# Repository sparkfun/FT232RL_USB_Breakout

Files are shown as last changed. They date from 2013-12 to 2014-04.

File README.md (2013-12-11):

FT232RL USB Breakout
====================

[FT232RL USB to Serial Breakout Board
*FT232RL USB to Serial Breakout Board (BOB-00718)*](https://www.sparkfun.com/products/718)

This is a basic breakout board for FTDI's popular USB to UART IC.
VCCIO is tied to 3.3V through a solder jumper. 

Repository Contents
-------------------
* **/Hardware** - All Eagle design files (.brd, .sch)

License Information
-------------------
The hardware is released under [Creative Commons Share-alike 3.0](http://creativecommons.org/licenses/by-sa/3.0/).  
All other code is open source so please feel free to do anything you want with it; you buy me a beer if you use this and we meet someday ([Beerware license](http://en.wikipedia.org/wiki/Beerware)).

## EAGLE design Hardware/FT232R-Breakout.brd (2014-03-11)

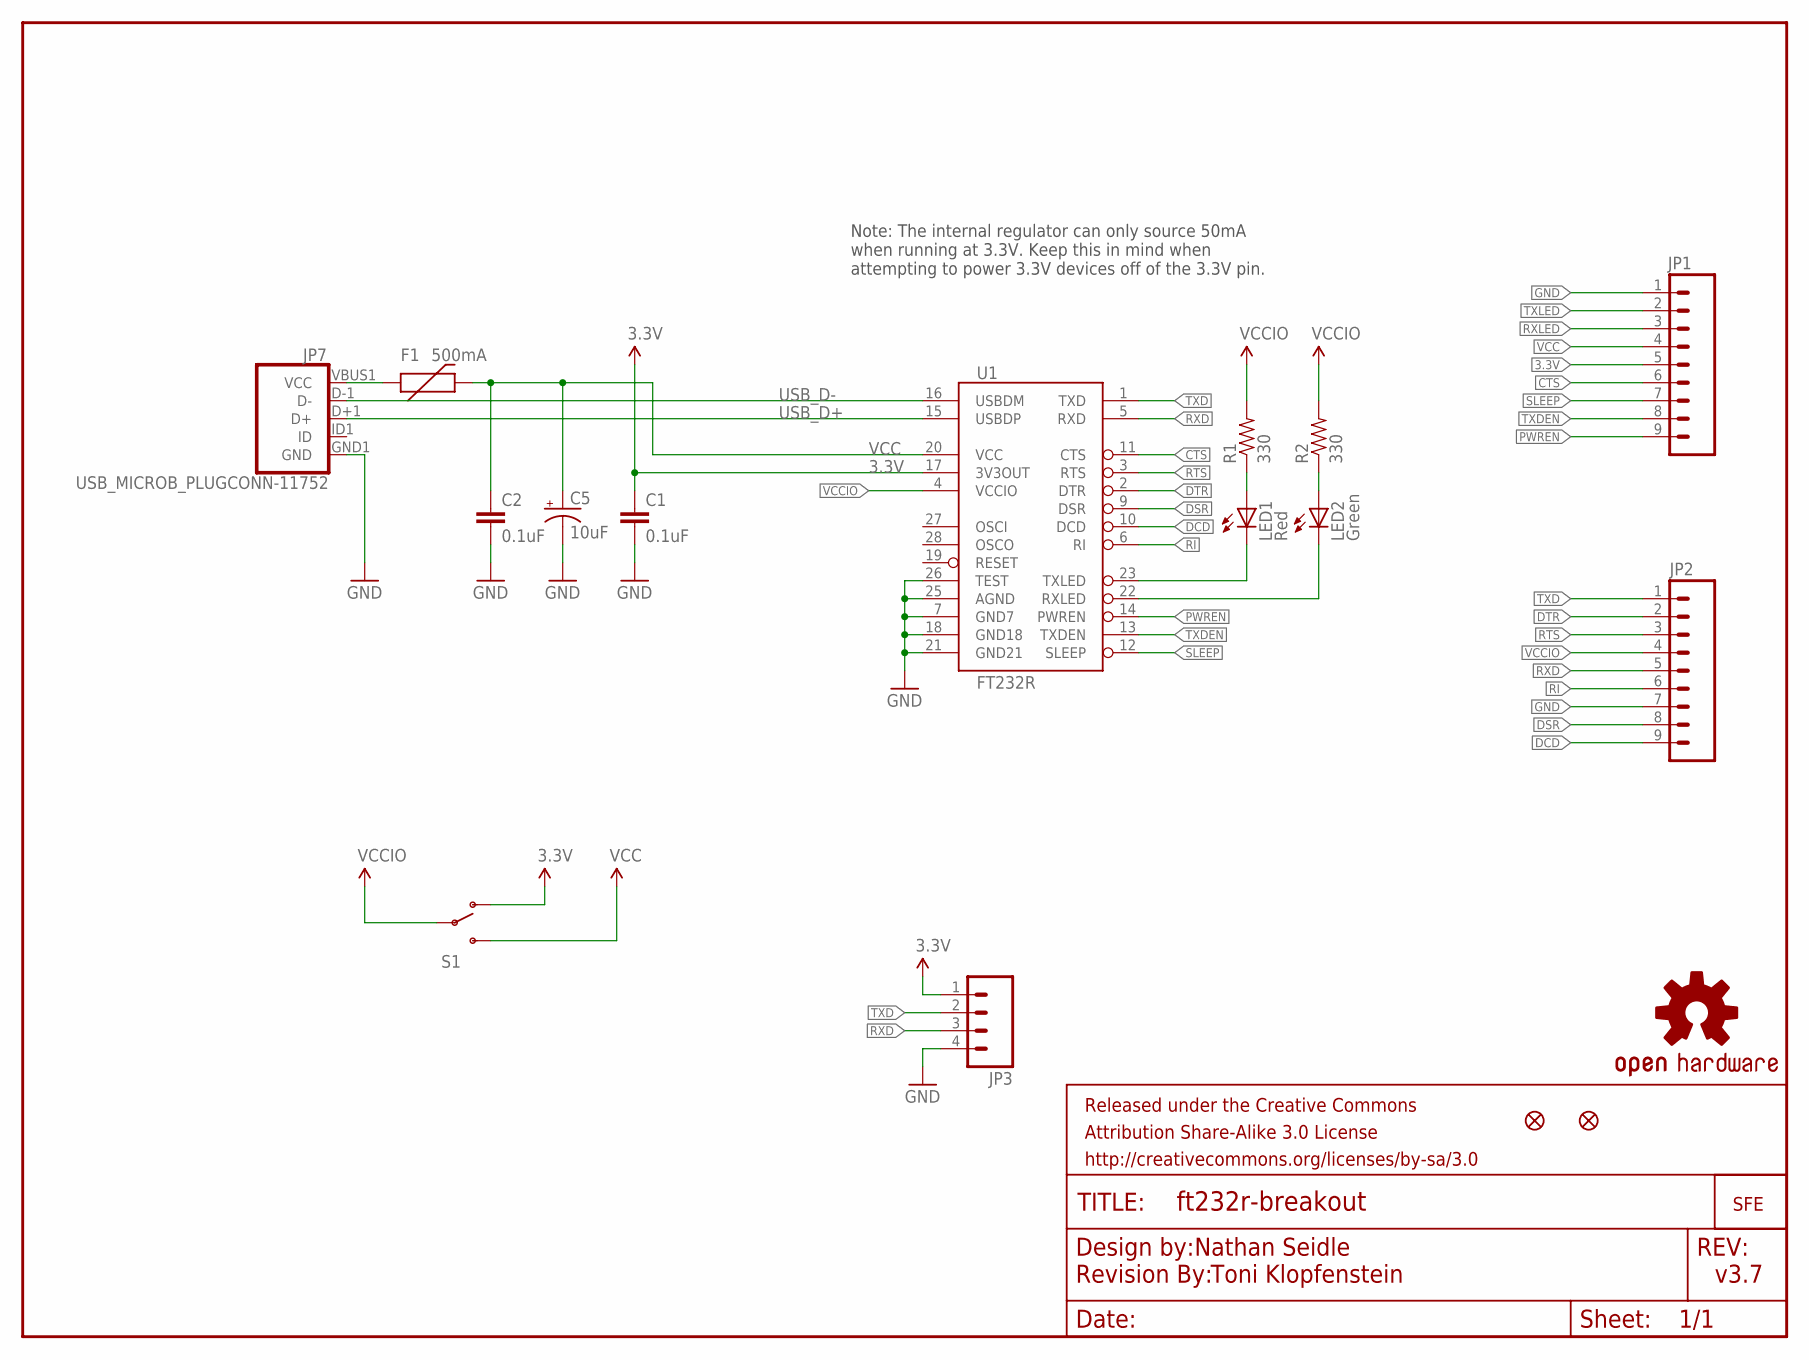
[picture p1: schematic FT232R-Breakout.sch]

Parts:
C1, C2: 0.1uF; 0603-CAP
C5: 10uF; EIA3216
F1: 500mA; PTC-1206
FRAME1: FRAME-LETTER; CREATIVE_COMMONS
JP1, JP2: M09; 1X09
JP3: M04PTH; 1X04
JP5, JP6: FIDUCIAL1X2; FIDUCIAL-1X2
JP7: USB_MICROB_PLUGCONN-11752; USB-B-MICRO-SMD_V03
LED1: Red; LED-0603
LED2: Green; LED-0603
LOGO1: OSHW-LOGOS; OSHW-LOGO-S
R1, R2: 330; 0603-RES
S1: SWITCH-SPDTSMD; AYZ0202
U1: FT232R; SSOP28DB
U$1: REVISION
U$2: LOGO-SFENEW; SFE-NEW-WEBLOGO

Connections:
3.3V: C1.1, JP1.5, JP3.1, S1.1 (O), U1.17 (3V3OUT)
CTS: JP1.6, U1.11 (CTS)
DCD: JP2.9, U1.10 (DCD)
DSR: JP2.8, U1.9 (DSR)
DTR: JP2.2, U1.2 (DTR)
GND: C1.2, C2.2, C5.C (-), JP1.1, JP2.7, JP3.4, JP7.GND1 (GND), U1.7 (GND7), U1.18 (GND18), U1.21 (GND21), U1.25 (AGND), U1.26 (TEST)
unnamed: LED1.A, R1.1
unnamed: LED2.A, R2.1
unnamed: F1.1, JP7.VBUS1 (VCC)
PWREN: JP1.9, U1.14 (PWREN)
RI: JP2.6, U1.6 (RI)
RTS: JP2.3, U1.3 (RTS)
RXD: JP2.5, JP3.3, U1.5 (RXD)
RXLED: JP1.3, LED2.C, U1.22 (RXLED)
SLEEP: JP1.7, U1.12 (SLEEP)
TXD: JP2.1, JP3.2, U1.1 (TXD)
TXDEN: JP1.8, U1.13 (TXDEN)
TXLED: JP1.2, LED1.C, U1.23 (TXLED)
USB_D+: JP7.D+1 (D+), U1.15 (USBDP)
USB_D-: JP7.D-1 (D-), U1.16 (USBDM)
VCC: C2.1, C5.A (+), F1.2, JP1.4, S1.3 (S), U1.20 (VCC)
VCCIO: JP2.4, R1.2, R2.2, S1.2, U1.4 (VCCIO)

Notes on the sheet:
v3.7
Nathan Seidle
Toni Klopfenstein
Note: The internal regulator can only source 50mA when running at 3.3V. Keep this in mind when attempting to power 3.3V devices off of the 3.3V pin.

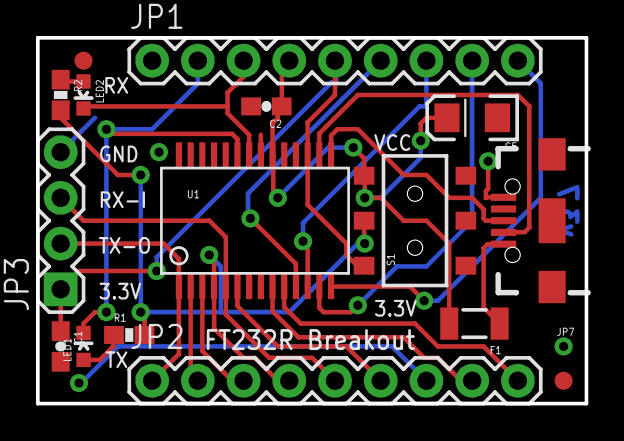
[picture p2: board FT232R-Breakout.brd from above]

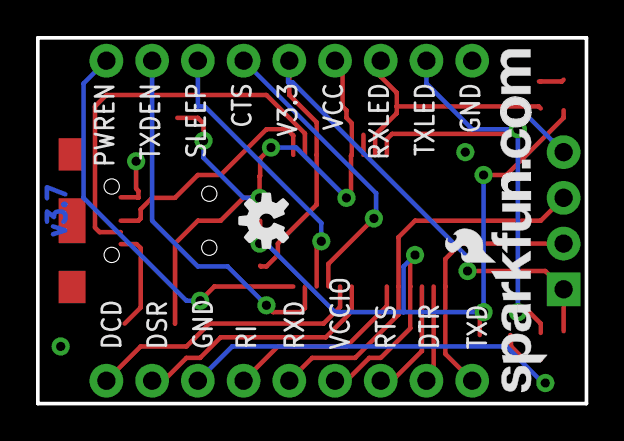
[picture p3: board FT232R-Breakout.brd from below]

Board: 2 copper layers, 30.5 x 20.3 mm, 20 parts (2 on the bottom side), 22 nets.

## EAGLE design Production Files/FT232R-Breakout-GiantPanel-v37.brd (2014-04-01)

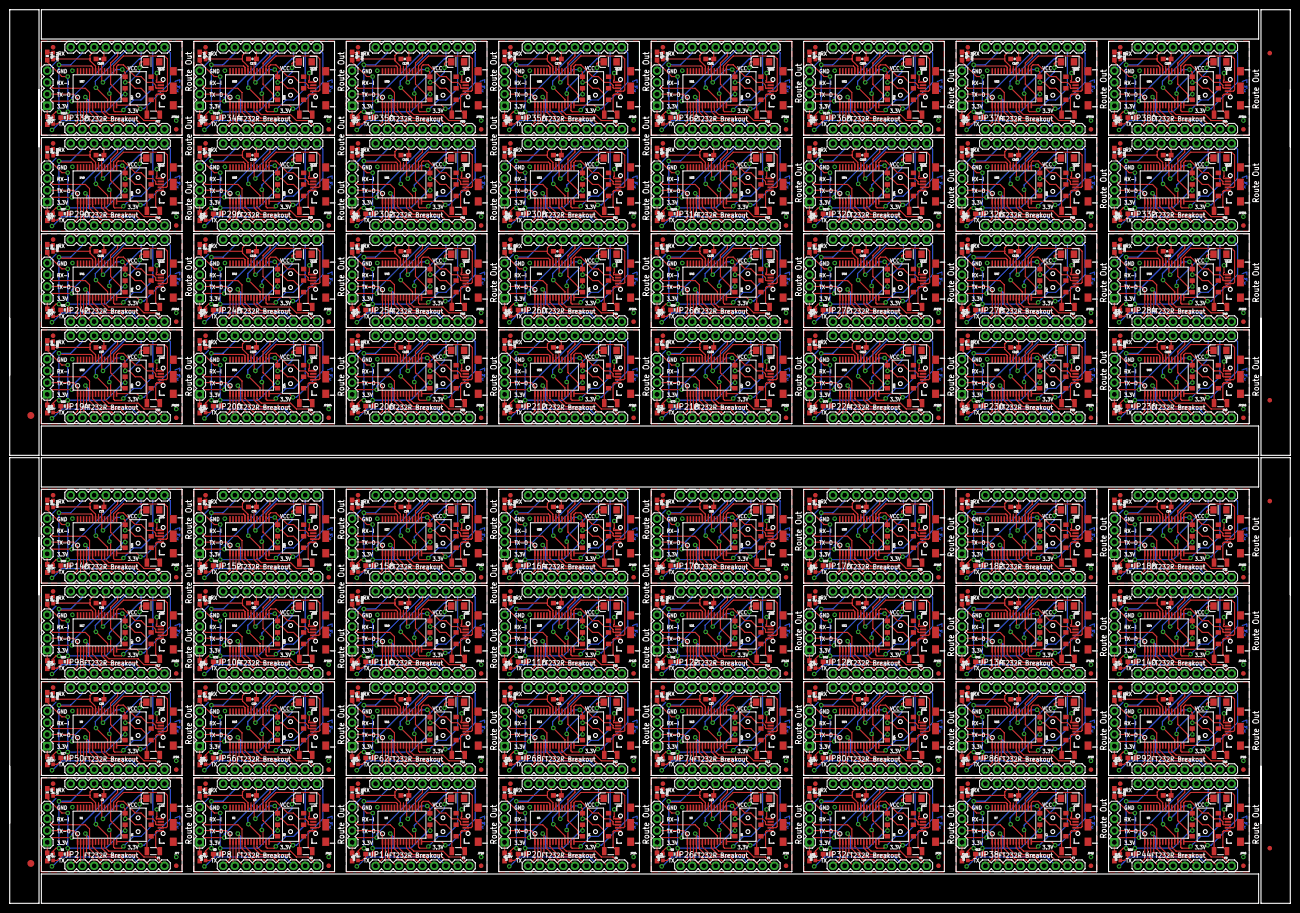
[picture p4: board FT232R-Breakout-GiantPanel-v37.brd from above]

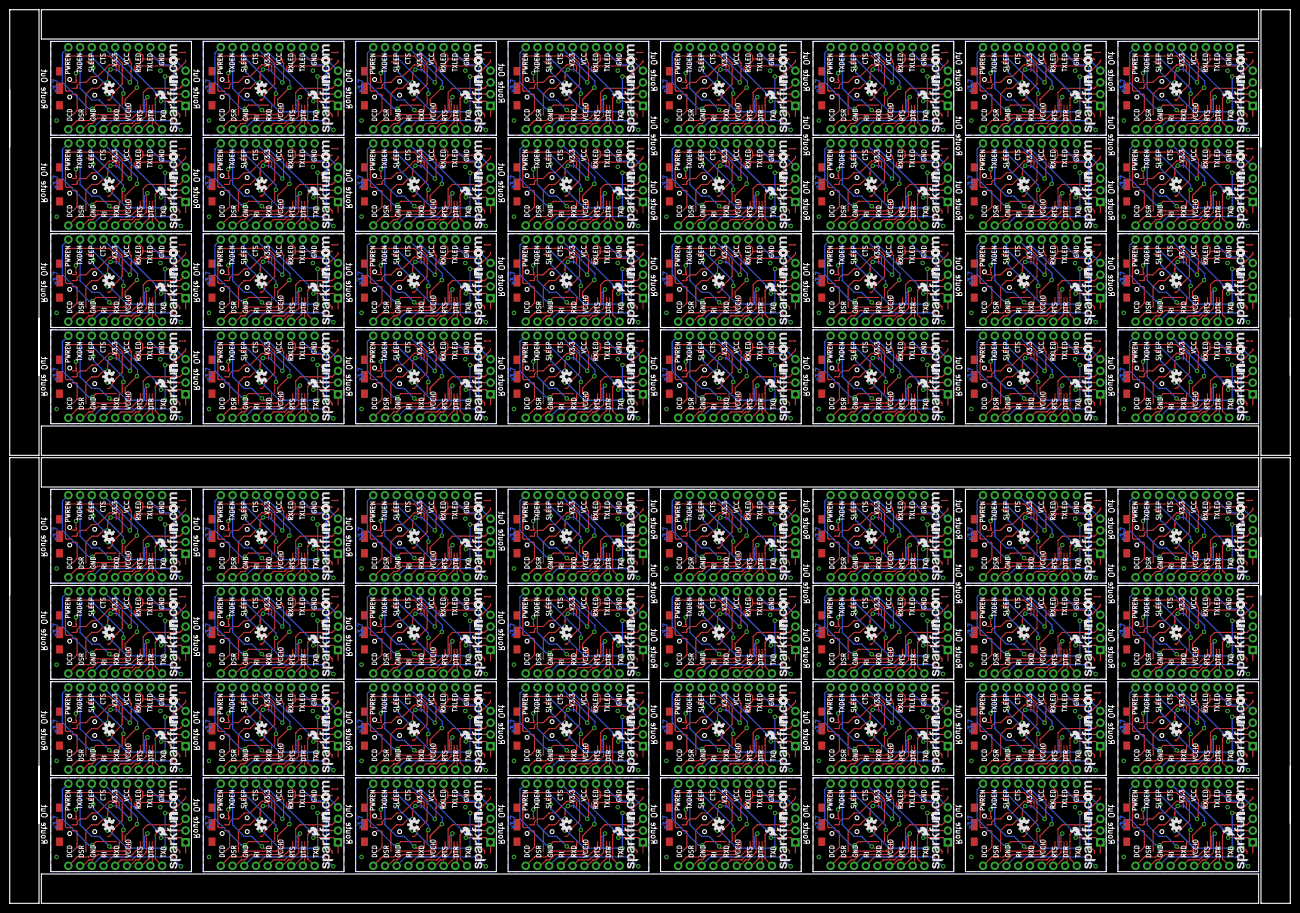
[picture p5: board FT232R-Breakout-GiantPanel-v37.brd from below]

Board: 2 copper layers, 277.4 x 193.5 mm, 1158 parts (128 on the bottom side), 1408 nets.

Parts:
C1, C2, C3, C6, C7, C9, C10, C12, C13, C15, C16, C18, C19, C21, C22, C24, C25, C27, C28, C30, C31, C33, C34, C36, C37, C39, C40, C42, C43, C45, C46, C48, C49, C51, C52, C54, C55, C57, C58, C60, C61, C63, C64, C66, C67, C69, C70, C72, C73, C75, C76, C78, C79, C81, C82, C84, C85, C87, C88, C90, C91, C93, C94, C96, C97, C99, C100, C102, C103, C105, C106, C108, C109, C111, C112, C114, C115, C117, C118, C120, C121, C123, C124, C126, C127, C129, C130, C132, C133, C135, C136, C138, C139, C141, C142, C144, C145, C147, C148, C150, C151, C153, C154, C156, C157, C159, C160, C162, C163, C165, C166, C168, C169, C171, C172, C174, C175, C177, C178, C180, C181, C183, C184, C186, C187, C189, C190, C192: 0.1uF; 0603-CAP
C4, C5, C8, C11, C14, C17, C20, C23, C26, C29, C32, C35, C38, C41, C44, C47, C50, C53, C56, C59, C62, C65, C68, C71, C74, C77, C80, C83, C86, C89, C92, C95, C98, C101, C104, C107, C110, C113, C116, C119, C122, C125, C128, C131, C134, C137, C140, C143, C146, C149, C152, C155, C158, C161, C164, C167, C170, C173, C176, C179, C182, C185, C188, C191: 10uF; EIA3216
E$1, E$4: FIDUCIAL-1.5X3
E$2, E$3, E$6, E$8: FIDUCIAL-1X2
F1, F2, F3, F4, F5, F6, F7, F8, F9, F10, F11, F12, F13, F14, F15, F16, F17, F18, F19, F20, F21, F22, F23, F24, F25, F26, F27, F28, F29, F30, F31, F32, F33, F34, F35, F36, F37, F38, F39, F40, F41, F42, F43, F44, F45, F46, F47, F48, F49, F50, F51, F52, F53, F54, F55, F56, F57, F58, F59, F60, F61, F62, F63, F64: 500mA; PTC-1206
JP1, JP2, JP4, JP8, JP13, JP14, JP19, JP20, JP25, JP26, JP31, JP32, JP37, JP38, JP43, JP44, JP49, JP50, JP55, JP56, JP61, JP62, JP67, JP68, JP73, JP74, JP79, JP80, JP85, JP86, JP91, JP92, JP97, JP98, JP103, JP104, JP109, JP110, JP115, JP116, JP121, JP122, JP127, JP128, JP133, JP134, JP139, JP140, JP145, JP146, JP151, JP152, JP157, JP158, JP163, JP164, JP169, JP170, JP175, JP176, JP181, JP182, JP187, JP188, JP193, JP194, JP199, JP200, JP205, JP206, JP211, JP212, JP217, JP218, JP223, JP224, JP229, JP230, JP235, JP236, JP241, JP242, JP247, JP248, JP253, JP254, JP259, JP260, JP265, JP266, JP271, JP272, JP277, JP278, JP283, JP284, JP289, JP290, JP295, JP296, JP301, JP302, JP307, JP308, JP313, JP314, JP319, JP320, JP325, JP326, JP331, JP332, JP337, JP338, JP343, JP344, JP349, JP350, JP355, JP356, JP361, JP362, JP367, JP368, JP373, JP374, JP379, JP380: 1X09
JP3, JP9, JP15, JP21, JP27, JP33, JP39, JP45, JP51, JP57, JP63, JP69, JP75, JP81, JP87, JP93, JP99, JP105, JP111, JP117, JP123, JP129, JP135, JP141, JP147, JP153, JP159, JP165, JP171, JP177, JP183, JP189, JP195, JP201, JP207, JP213, JP219, JP225, JP231, JP237, JP243, JP249, JP255, JP261, JP267, JP273, JP279, JP285, JP291, JP297, JP303, JP309, JP315, JP321, JP327, JP333, JP339, JP345, JP351, JP357, JP363, JP369, JP375, JP381: 1X04
JP5, JP6, JP10, JP11, JP16, JP17, JP22, JP23, JP28, JP29, JP34, JP35, JP40, JP41, JP46, JP47, JP52, JP53, JP58, JP59, JP64, JP65, JP70, JP71, JP76, JP77, JP82, JP83, JP88, JP89, JP94, JP95, JP100, JP101, JP106, JP107, JP112, JP113, JP118, JP119, JP124, JP125, JP130, JP131, JP136, JP137, JP142, JP143, JP148, JP149, JP154, JP155, JP160, JP161, JP166, JP167, JP172, JP173, JP178, JP179, JP184, JP185, JP190, JP191, JP196, JP197, JP202, JP203, JP208, JP209, JP214, JP215, JP220, JP221, JP226, JP227, JP232, JP233, JP238, JP239, JP244, JP245, JP250, JP251, JP256, JP257, JP262, JP263, JP268, JP269, JP274, JP275, JP280, JP281, JP286, JP287, JP292, JP293, JP298, JP299, JP304, JP305, JP310, JP311, JP316, JP317, JP322, JP323, JP328, JP329, JP334, JP335, JP340, JP341, JP346, JP347, JP352, JP353, JP358, JP359, JP364, JP365, JP370, JP371, JP376, JP377, JP382, JP383: FIDUCIAL1X2; FIDUCIAL-1X2
JP7, JP12, JP18, JP24, JP30, JP36, JP42, JP48, JP54, JP60, JP66, JP72, JP78, JP84, JP90, JP96, JP102, JP108, JP114, JP120, JP126, JP132, JP138, JP144, JP150, JP156, JP162, JP168, JP174, JP180, JP186, JP192, JP198, JP204, JP210, JP216, JP222, JP228, JP234, JP240, JP246, JP252, JP258, JP264, JP270, JP276, JP282, JP288, JP294, JP300, JP306, JP312, JP318, JP324, JP330, JP336, JP342, JP348, JP354, JP360, JP366, JP372, JP378, JP384: USB_MICROB_PLUGCONN-11752; USB-B-MICRO-SMD_V03
LED1, LED3, LED5, LED7, LED9, LED11, LED13, LED15, LED17, LED19, LED21, LED23, LED25, LED27, LED29, LED31, LED33, LED35, LED37, LED39, LED41, LED43, LED45, LED47, LED49, LED51, LED53, LED55, LED57, LED59, LED61, LED63, LED65, LED67, LED69, LED71, LED73, LED75, LED77, LED79, LED81, LED83, LED85, LED87, LED89, LED91, LED93, LED95, LED97, LED99, LED101, LED103, LED105, LED107, LED109, LED111, LED113, LED115, LED117, LED119, LED121, LED123, LED125, LED127: Red; LED-0603
LED2, LED4, LED6, LED8, LED10, LED12, LED14, LED16, LED18, LED20, LED22, LED24, LED26, LED28, LED30, LED32, LED34, LED36, LED38, LED40, LED42, LED44, LED46, LED48, LED50, LED52, LED54, LED56, LED58, LED60, LED62, LED64, LED66, LED68, LED70, LED72, LED74, LED76, LED78, LED80, LED82, LED84, LED86, LED88, LED90, LED92, LED94, LED96, LED98, LED100, LED102, LED104, LED106, LED108, LED110, LED112, LED114, LED116, LED118, LED120, LED122, LED124, LED126, LED128: Green; LED-0603
LOGO1, LOGO2, LOGO3, LOGO4, LOGO5, LOGO6, LOGO7, LOGO8, LOGO9, LOGO10, LOGO11, LOGO12, LOGO13, LOGO14, LOGO15, LOGO16, LOGO17, LOGO18, LOGO19, LOGO20, LOGO21, LOGO22, LOGO23, LOGO24, LOGO25, LOGO26, LOGO27, LOGO28, LOGO29, LOGO30, LOGO31, LOGO32, LOGO33, LOGO34, LOGO35, LOGO36, LOGO37, LOGO38, LOGO39, LOGO40, LOGO41, LOGO42, LOGO43, LOGO44, LOGO45, LOGO46, LOGO47, LOGO48, LOGO49, LOGO50, LOGO51, LOGO52, LOGO53, LOGO54, LOGO55, LOGO56, LOGO57, LOGO58, LOGO59, LOGO60, LOGO61, LOGO62, LOGO63, LOGO64: OSHW-LOGOS; OSHW-LOGO-S
R1, R2, R3, R4, R5, R6, R7, R8, R9, R10, R11, R12, R13, R14, R15, R16, R17, R18, R19, R20, R21, R22, R23, R24, R25, R26, R27, R28, R29, R30, R31, R32, R33, R34, R35, R36, R37, R38, R39, R40, R41, R42, R43, R44, R45, R46, R47, R48, R49, R50, R51, R52, R53, R54, R55, R56, R57, R58, R59, R60, R61, R62, R63, R64, R65, R66, R67, R68, R69, R70, R71, R72, R73, R74, R75, R76, R77, R78, R79, R80, R81, R82, R83, R84, R85, R86, R87, R88, R89, R90, R91, R92, R93, R94, R95, R96, R97, R98, R99, R100, R101, R102, R103, R104, R105, R106, R107, R108, R109, R110, R111, R112, R113, R114, R115, R116, R117, R118, R119, R120, R121, R122, R123, R124, R125, R126, R127, R128: 330; 0603-RES
S1, S2, S3, S4, S5, S6, S7, S8, S9, S10, S11, S12, S13, S14, S15, S16, S17, S18, S19, S20, S21, S22, S23, S24, S25, S26, S27, S28, S29, S30, S31, S32, S33, S34, S35, S36, S37, S38, S39, S40, S41, S42, S43, S44, S45, S46, S47, S48, S49, S50, S51, S52, S53, S54, S55, S56, S57, S58, S59, S60, S61, S62, S63, S64: AYZ0202
U1, U2, U3, U4, U5, U6, U7, U8, U9, U10, U11, U12, U13, U14, U15, U16, U17, U18, U19, U20, U21, U22, U23, U24, U25, U26, U27, U28, U29, U30, U31, U32, U33, U34, U35, U36, U37, U38, U39, U40, U41, U42, U43, U44, U45, U46, U47, U48, U49, U50, U51, U52, U53, U54, U55, U56, U57, U58, U59, U60, U61, U62, U63, U64: FT232R; SSOP28DB
U$1, U$2, U$3, U$4, U$5, U$6, U$7, U$8, U$9, U$10, U$11, U$12, U$13, U$14, U$15, U$16, U$17, U$18, U$19, U$20, U$21, U$22, U$23, U$24, U$25, U$26, U$27, U$28, U$29, U$30, U$31, U$32, U$33, U$34, U$35, U$36, U$37, U$38, U$39, U$40, U$41, U$42, U$43, U$44, U$45, U$46, U$47, U$48, U$49, U$50, U$51, U$52, U$53, U$54, U$55, U$56, U$57, U$58, U$59, U$60, U$61, U$62, U$63, U$64: LOGO-SFENEW; SFE-NEW-WEBLOGO

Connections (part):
3.3V: C1.1, JP1.5, JP3.1, S1.1, U1.17
3.3V1: C6.1, JP4.5, JP9.1, S2.1, U2.17
3.3V2: C9.1, JP13.5, JP15.1, S3.1, U3.17
3.3V3: C12.1, JP19.5, JP21.1, S4.1, U4.17
3.3V4: C15.1, JP25.5, JP27.1, S5.1, U5.17
3.3V5: C18.1, JP31.5, JP33.1, S6.1, U6.17
3.3V6: C21.1, JP37.5, JP39.1, S7.1, U7.17
3.3V7: C24.1, JP43.5, JP45.1, S8.1, U8.17
3.3V8: C27.1, JP49.5, JP51.1, S9.1, U9.17
3.3V9: C30.1, JP55.5, JP57.1, S10.1, U10.17
3.3V10: C33.1, JP61.5, JP63.1, S11.1, U11.17
3.3V11: C36.1, JP67.5, JP69.1, S12.1, U12.17
3.3V12: C39.1, JP73.5, JP75.1, S13.1, U13.17
3.3V13: C42.1, JP79.5, JP81.1, S14.1, U14.17
3.3V14: C45.1, JP85.5, JP87.1, S15.1, U15.17
3.3V15: C48.1, JP91.5, JP93.1, S16.1, U16.17
3.3V16: C51.1, JP97.5, JP99.1, S17.1, U17.17
3.3V17: C54.1, JP103.5, JP105.1, S18.1, U18.17
3.3V18: C57.1, JP109.5, JP111.1, S19.1, U19.17
3.3V19: C60.1, JP115.5, JP117.1, S20.1, U20.17
3.3V20: C63.1, JP121.5, JP123.1, S21.1, U21.17
3.3V21: C66.1, JP127.5, JP129.1, S22.1, U22.17
3.3V22: C69.1, JP133.5, JP135.1, S23.1, U23.17
3.3V23: C72.1, JP139.5, JP141.1, S24.1, U24.17
3.3V24: C75.1, JP145.5, JP147.1, S25.1, U25.17
3.3V25: C78.1, JP151.5, JP153.1, S26.1, U26.17
3.3V26: C81.1, JP157.5, JP159.1, S27.1, U27.17
3.3V27: C84.1, JP163.5, JP165.1, S28.1, U28.17
3.3V28: C87.1, JP169.5, JP171.1, S29.1, U29.17
3.3V29: C90.1, JP175.5, JP177.1, S30.1, U30.17
3.3V30: C93.1, JP181.5, JP183.1, S31.1, U31.17
3.3V31: C96.1, JP187.5, JP189.1, S32.1, U32.17
3.3V32: C99.1, JP193.5, JP195.1, S33.1, U33.17
3.3V33: C102.1, JP199.5, JP201.1, S34.1, U34.17
3.3V34: C105.1, JP205.5, JP207.1, S35.1, U35.17
3.3V35: C108.1, JP211.5, JP213.1, S36.1, U36.17
3.3V36: C111.1, JP217.5, JP219.1, S37.1, U37.17
3.3V37: C114.1, JP223.5, JP225.1, S38.1, U38.17
3.3V38: C117.1, JP229.5, JP231.1, S39.1, U39.17
3.3V39: C120.1, JP235.5, JP237.1, S40.1, U40.17
3.3V40: C123.1, JP241.5, JP243.1, S41.1, U41.17
3.3V41: C126.1, JP247.5, JP249.1, S42.1, U42.17
3.3V42: C129.1, JP253.5, JP255.1, S43.1, U43.17
3.3V43: C132.1, JP259.5, JP261.1, S44.1, U44.17
3.3V44: C135.1, JP265.5, JP267.1, S45.1, U45.17
3.3V45: C138.1, JP271.5, JP273.1, S46.1, U46.17
3.3V46: C141.1, JP277.5, JP279.1, S47.1, U47.17
3.3V47: C144.1, JP283.5, JP285.1, S48.1, U48.17
3.3V48: C147.1, JP289.5, JP291.1, S49.1, U49.17
3.3V49: C150.1, JP295.5, JP297.1, S50.1, U50.17
3.3V50: C153.1, JP301.5, JP303.1, S51.1, U51.17
3.3V51: C156.1, JP307.5, JP309.1, S52.1, U52.17
3.3V52: C159.1, JP313.5, JP315.1, S53.1, U53.17
3.3V53: C162.1, JP319.5, JP321.1, S54.1, U54.17
3.3V54: C165.1, JP325.5, JP327.1, S55.1, U55.17
3.3V55: C168.1, JP331.5, JP333.1, S56.1, U56.17
3.3V56: C171.1, JP337.5, JP339.1, S57.1, U57.17
3.3V57: C174.1, JP343.5, JP345.1, S58.1, U58.17
3.3V58: C177.1, JP349.5, JP351.1, S59.1, U59.17
3.3V59: C180.1, JP355.5, JP357.1, S60.1, U60.17
3.3V60: C183.1, JP361.5, JP363.1, S61.1, U61.17
3.3V61: C186.1, JP367.5, JP369.1, S62.1, U62.17
3.3V62: C189.1, JP373.5, JP375.1, S63.1, U63.17
3.3V63: C192.1, JP379.5, JP381.1, S64.1, U64.17
CTS: JP1.6, U1.11
CTS1: JP4.6, U2.11
CTS2: JP13.6, U3.11
CTS3: JP19.6, U4.11
CTS4: JP25.6, U5.11
CTS5: JP31.6, U6.11
CTS6: JP37.6, U7.11
CTS7: JP43.6, U8.11
CTS8: JP49.6, U9.11
CTS9: JP55.6, U10.11
CTS10: JP61.6, U11.11
CTS11: JP67.6, U12.11
CTS12: JP73.6, U13.11
CTS13: JP79.6, U14.11
CTS14: JP85.6, U15.11
CTS15: JP91.6, U16.11
CTS16: JP97.6, U17.11
CTS17: JP103.6, U18.11
CTS18: JP109.6, U19.11
CTS19: JP115.6, U20.11
CTS20: JP121.6, U21.11
CTS21: JP127.6, U22.11
CTS22: JP133.6, U23.11
CTS23: JP139.6, U24.11
CTS24: JP145.6, U25.11
CTS25: JP151.6, U26.11
CTS26: JP157.6, U27.11
CTS27: JP163.6, U28.11
CTS28: JP169.6, U29.11
CTS29: JP175.6, U30.11
CTS30: JP181.6, U31.11
CTS31: JP187.6, U32.11
CTS32: JP193.6, U33.11
CTS33: JP199.6, U34.11
CTS34: JP205.6, U35.11
CTS35: JP211.6, U36.11
CTS36: JP217.6, U37.11
CTS37: JP223.6, U38.11
CTS38: JP229.6, U39.11
CTS39: JP235.6, U40.11
CTS40: JP241.6, U41.11
CTS41: JP247.6, U42.11
CTS42: JP253.6, U43.11
CTS43: JP259.6, U44.11
CTS44: JP265.6, U45.11
CTS45: JP271.6, U46.11
CTS46: JP277.6, U47.11
CTS47: JP283.6, U48.11
CTS48: JP289.6, U49.11
CTS49: JP295.6, U50.11
CTS50: JP301.6, U51.11
CTS51: JP307.6, U52.11
CTS52: JP313.6, U53.11
CTS53: JP319.6, U54.11
CTS54: JP325.6, U55.11
CTS55: JP331.6, U56.11
CTS56: JP337.6, U57.11
CTS57: JP343.6, U58.11
CTS58: JP349.6, U59.11
CTS59: JP355.6, U60.11
CTS60: JP361.6, U61.11
CTS61: JP367.6, U62.11
CTS62: JP373.6, U63.11
CTS63: JP379.6, U64.11
DCD: JP2.9, U1.10
DCD1: JP8.9, U2.10
DCD2: JP14.9, U3.10
DCD3: JP20.9, U4.10
DCD4: JP26.9, U5.10
DCD5: JP32.9, U6.10
DCD6: JP38.9, U7.10
DCD7: JP44.9, U8.10
DCD8: JP50.9, U9.10
DCD9: JP56.9, U10.10
DCD10: JP62.9, U11.10
DCD11: JP68.9, U12.10
DCD12: JP74.9, U13.10
DCD13: JP80.9, U14.10
DCD14: JP86.9, U15.10
DCD15: JP92.9, U16.10
DCD16: JP98.9, U17.10
DCD17: JP104.9, U18.10
DCD18: JP110.9, U19.10
DCD19: JP116.9, U20.10
DCD20: JP122.9, U21.10
DCD21: JP128.9, U22.10
DCD22: JP134.9, U23.10
DCD23: JP140.9, U24.10
DCD24: JP146.9, U25.10
DCD25: JP152.9, U26.10
DCD26: JP158.9, U27.10
DCD27: JP164.9, U28.10
DCD28: JP170.9, U29.10
DCD29: JP176.9, U30.10
DCD30: JP182.9, U31.10
DCD31: JP188.9, U32.10
DCD32: JP194.9, U33.10
DCD33: JP200.9, U34.10
DCD34: JP206.9, U35.10
DCD35: JP212.9, U36.10
DCD36: JP218.9, U37.10
DCD37: JP224.9, U38.10
DCD38: JP230.9, U39.10
DCD39: JP236.9, U40.10
DCD40: JP242.9, U41.10
DCD41: JP248.9, U42.10
DCD42: JP254.9, U43.10
DCD43: JP260.9, U44.10
DCD44: JP266.9, U45.10
DCD45: JP272.9, U46.10
DCD46: JP278.9, U47.10
DCD47: JP284.9, U48.10
DCD48: JP290.9, U49.10
DCD49: JP296.9, U50.10
DCD50: JP302.9, U51.10
DCD51: JP308.9, U52.10
DCD52: JP314.9, U53.10
DCD53: JP320.9, U54.10
DCD54: JP326.9, U55.10
DCD55: JP332.9, U56.10
DCD56: JP338.9, U57.10
DCD57: JP344.9, U58.10
DCD58: JP350.9, U59.10
DCD59: JP356.9, U60.10
DCD60: JP362.9, U61.10
DCD61: JP368.9, U62.10
DCD62: JP374.9, U63.10
DCD63: JP380.9, U64.10
DSR: JP2.8, U1.9
DSR1: JP8.8, U2.9
DSR2: JP14.8, U3.9
DSR3: JP20.8, U4.9
DSR4: JP26.8, U5.9
DSR5: JP32.8, U6.9
DSR6: JP38.8, U7.9
DSR7: JP44.8, U8.9
DSR8: JP50.8, U9.9
DSR9: JP56.8, U10.9
DSR10: JP62.8, U11.9
DSR11: JP68.8, U12.9
DSR12: JP74.8, U13.9
DSR13: JP80.8, U14.9
DSR14: JP86.8, U15.9
DSR15: JP92.8, U16.9
DSR16: JP98.8, U17.9
DSR17: JP104.8, U18.9
DSR18: JP110.8, U19.9
DSR19: JP116.8, U20.9
DSR20: JP122.8, U21.9
DSR21: JP128.8, U22.9
DSR22: JP134.8, U23.9
DSR23: JP140.8, U24.9
DSR24: JP146.8, U25.9
DSR25: JP152.8, U26.9
DSR26: JP158.8, U27.9
DSR27: JP164.8, U28.9
DSR28: JP170.8, U29.9
DSR29: JP176.8, U30.9
DSR30: JP182.8, U31.9
DSR31: JP188.8, U32.9
DSR32: JP194.8, U33.9
DSR33: JP200.8, U34.9
DSR34: JP206.8, U35.9
DSR35: JP212.8, U36.9
DSR36: JP218.8, U37.9
DSR37: JP224.8, U38.9
DSR38: JP230.8, U39.9
DSR39: JP236.8, U40.9
DSR40: JP242.8, U41.9
DSR41: JP248.8, U42.9
DSR42: JP254.8, U43.9
DSR43: JP260.8, U44.9
DSR44: JP266.8, U45.9
DSR45: JP272.8, U46.9
DSR46: JP278.8, U47.9
DSR47: JP284.8, U48.9
DSR48: JP290.8, U49.9
DSR49: JP296.8, U50.9
DSR50: JP302.8, U51.9
DSR51: JP308.8, U52.9
DSR52: JP314.8, U53.9
DSR53: JP320.8, U54.9
DSR54: JP326.8, U55.9
DSR55: JP332.8, U56.9
DSR56: JP338.8, U57.9
DSR57: JP344.8, U58.9
DSR58: JP350.8, U59.9
DSR59: JP356.8, U60.9
DSR60: JP362.8, U61.9
DSR61: JP368.8, U62.9
DSR62: JP374.8, U63.9
DSR63: JP380.8, U64.9
DTR: JP2.2, U1.2
DTR1: JP8.2, U2.2
DTR2: JP14.2, U3.2
DTR3: JP20.2, U4.2
DTR4: JP26.2, U5.2
DTR5: JP32.2, U6.2
DTR6: JP38.2, U7.2
DTR7: JP44.2, U8.2
DTR8: JP50.2, U9.2
DTR9: JP56.2, U10.2
DTR10: JP62.2, U11.2
DTR11: JP68.2, U12.2
DTR12: JP74.2, U13.2
DTR13: JP80.2, U14.2
DTR14: JP86.2, U15.2
DTR15: JP92.2, U16.2
DTR16: JP98.2, U17.2
DTR17: JP104.2, U18.2
DTR18: JP110.2, U19.2
DTR19: JP116.2, U20.2
DTR20: JP122.2, U21.2
DTR21: JP128.2, U22.2
DTR22: JP134.2, U23.2
DTR23: JP140.2, U24.2
DTR24: JP146.2, U25.2
DTR25: JP152.2, U26.2
DTR26: JP158.2, U27.2
DTR27: JP164.2, U28.2
DTR28: JP170.2, U29.2
DTR29: JP176.2, U30.2
DTR30: JP182.2, U31.2
DTR31: JP188.2, U32.2
DTR32: JP194.2, U33.2
DTR33: JP200.2, U34.2
DTR34: JP206.2, U35.2
DTR35: JP212.2, U36.2
DTR36: JP218.2, U37.2
DTR37: JP224.2, U38.2
DTR38: JP230.2, U39.2
DTR39: JP236.2, U40.2
DTR40: JP242.2, U41.2
DTR41: JP248.2, U42.2
DTR42: JP254.2, U43.2
DTR43: JP260.2, U44.2
DTR44: JP266.2, U45.2
DTR45: JP272.2, U46.2
DTR46: JP278.2, U47.2
DTR47: JP284.2, U48.2
DTR48: JP290.2, U49.2
DTR49: JP296.2, U50.2
DTR50: JP302.2, U51.2
DTR51: JP308.2, U52.2
DTR52: JP314.2, U53.2
DTR53: JP320.2, U54.2
DTR54: JP326.2, U55.2
DTR55: JP332.2, U56.2
DTR56: JP338.2, U57.2
DTR57: JP344.2, U58.2
DTR58: JP350.2, U59.2
DTR59: JP356.2, U60.2
DTR60: JP362.2, U61.2
DTR61: JP368.2, U62.2
DTR62: JP374.2, U63.2
DTR63: JP380.2, U64.2
GND: C1.2, C2.2, C5.C, JP1.1, JP2.7, JP3.4, JP7.GND1, U1.7, U1.18, U1.21, U1.25, U1.26
GND1: C3.2, C4.C, C6.2, JP4.1, JP8.7, JP9.4, JP12.GND1, U2.7, U2.18, U2.21, U2.25, U2.26
GND2: C7.2, C8.C, C9.2, JP13.1, JP14.7, JP15.4, JP18.GND1, U3.7, U3.18, U3.21, U3.25, U3.26
GND3: C10.2, C11.C, C12.2, JP19.1, JP20.7, JP21.4, JP24.GND1, U4.7, U4.18, U4.21, U4.25, U4.26
GND4: C13.2, C14.C, C15.2, JP25.1, JP26.7, JP27.4, JP30.GND1, U5.7, U5.18, U5.21, U5.25, U5.26
GND5: C16.2, C17.C, C18.2, JP31.1, JP32.7, JP33.4, JP36.GND1, U6.7, U6.18, U6.21, U6.25, U6.26
GND6: C19.2, C20.C, C21.2, JP37.1, JP38.7, JP39.4, JP42.GND1, U7.7, U7.18, U7.21, U7.25, U7.26
GND7: C22.2, C23.C, C24.2, JP43.1, JP44.7, JP45.4, JP48.GND1, U8.7, U8.18, U8.21, U8.25, U8.26
GND8: C25.2, C26.C, C27.2, JP49.1, JP50.7, JP51.4, JP54.GND1, U9.7, U9.18, U9.21, U9.25, U9.26
GND9: C28.2, C29.C, C30.2, JP55.1, JP56.7, JP57.4, JP60.GND1, U10.7, U10.18, U10.21, U10.25, U10.26
GND10: C31.2, C32.C, C33.2, JP61.1, JP62.7, JP63.4, JP66.GND1, U11.7, U11.18, U11.21, U11.25, U11.26
GND11: C34.2, C35.C, C36.2, JP67.1, JP68.7, JP69.4, JP72.GND1, U12.7, U12.18, U12.21, U12.25, U12.26
GND12: C37.2, C38.C, C39.2, JP73.1, JP74.7, JP75.4, JP78.GND1, U13.7, U13.18, U13.21, U13.25, U13.26
GND13: C40.2, C41.C, C42.2, JP79.1, JP80.7, JP81.4, JP84.GND1, U14.7, U14.18, U14.21, U14.25, U14.26
GND14: C43.2, C44.C, C45.2, JP85.1, JP86.7, JP87.4, JP90.GND1, U15.7, U15.18, U15.21, U15.25, U15.26
GND15: C46.2, C47.C, C48.2, JP91.1, JP92.7, JP93.4, JP96.GND1, U16.7, U16.18, U16.21, U16.25, U16.26
GND16: C49.2, C50.C, C51.2, JP97.1, JP98.7, JP99.4, JP102.GND1, U17.7, U17.18, U17.21, U17.25, U17.26
GND17: C52.2, C53.C, C54.2, JP103.1, JP104.7, JP105.4, JP108.GND1, U18.7, U18.18, U18.21, U18.25, U18.26
GND18: C55.2, C56.C, C57.2, JP109.1, JP110.7, JP111.4, JP114.GND1, U19.7, U19.18, U19.21, U19.25, U19.26
GND19: C58.2, C59.C, C60.2, JP115.1, JP116.7, JP117.4, JP120.GND1, U20.7, U20.18, U20.21, U20.25, U20.26
GND20: C61.2, C62.C, C63.2, JP121.1, JP122.7, JP123.4, JP126.GND1, U21.7, U21.18, U21.21, U21.25, U21.26
GND21: C64.2, C65.C, C66.2, JP127.1, JP128.7, JP129.4, JP132.GND1, U22.7, U22.18, U22.21, U22.25, U22.26
GND22: C67.2, C68.C, C69.2, JP133.1, JP134.7, JP135.4, JP138.GND1, U23.7, U23.18, U23.21, U23.25, U23.26
GND23: C70.2, C71.C, C72.2, JP139.1, JP140.7, JP141.4, JP144.GND1, U24.7, U24.18, U24.21, U24.25, U24.26
GND24: C73.2, C74.C, C75.2, JP145.1, JP146.7, JP147.4, JP150.GND1, U25.7, U25.18, U25.21, U25.25, U25.26
GND25: C76.2, C77.C, C78.2, JP151.1, JP152.7, JP153.4, JP156.GND1, U26.7, U26.18, U26.21, U26.25, U26.26
GND26: C79.2, C80.C, C81.2, JP157.1, JP158.7, JP159.4, JP162.GND1, U27.7, U27.18, U27.21, U27.25, U27.26
GND27: C82.2, C83.C, C84.2, JP163.1, JP164.7, JP165.4, JP168.GND1, U28.7, U28.18, U28.21, U28.25, U28.26
GND28: C85.2, C86.C, C87.2, JP169.1, JP170.7, JP171.4, JP174.GND1, U29.7, U29.18, U29.21, U29.25, U29.26
GND29: C88.2, C89.C, C90.2, JP175.1, JP176.7, JP177.4, JP180.GND1, U30.7, U30.18, U30.21, U30.25, U30.26
GND30: C91.2, C92.C, C93.2, JP181.1, JP182.7, JP183.4, JP186.GND1, U31.7, U31.18, U31.21, U31.25, U31.26
GND31: C94.2, C95.C, C96.2, JP187.1, JP188.7, JP189.4, JP192.GND1, U32.7, U32.18, U32.21, U32.25, U32.26
GND32: C97.2, C98.C, C99.2, JP193.1, JP194.7, JP195.4, JP198.GND1, U33.7, U33.18, U33.21, U33.25, U33.26
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

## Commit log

2013-12-11 Adding hardware files and updating README
    [FT232R-Breakout-v36.brd, FT232R-Breakout-v36.sch]
2014-01-25 Adding v3.7 files
    [FT232R-Breakout-v36.brd, FT232R-Breakout-v36.sch, FT232R-Breakout.brd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]
2014-01-29 Adding SMD switch for 3.3V/ 5V selection
    [FT232R-Breakout.brd, FT232R-Breakout.sch]
2014-03-06 Removing paste spot left over from last version
    [FT232R-Breakout.brd]
2014-03-07 Centering USB connector
    [FT232R-Breakout.brd]
2014-03-11 Updating rev with recommendations from review
    [FT232R-Breakout.brd, FT232R-Breakout.sch]
2014-04-01 created giant panel v37
    [FT232R-Breakout-GiantPanel-v37.brd]

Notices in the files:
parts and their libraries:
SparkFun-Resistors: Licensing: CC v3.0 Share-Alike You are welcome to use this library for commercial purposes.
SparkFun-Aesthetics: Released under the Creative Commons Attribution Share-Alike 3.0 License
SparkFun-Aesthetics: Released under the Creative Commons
